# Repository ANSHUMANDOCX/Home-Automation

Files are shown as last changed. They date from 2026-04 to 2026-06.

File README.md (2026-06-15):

# ESP32 Home automation
## Description 
- This is a ESP32 S3 Based Home Automation devices which has 6 Relay switches that can be controlled over the web 
- It also has a BME280 Sensor for monitoring temprature,humidity and pressure in the realtime and can be monitored using a mobile app or a Webpage.
- Also had a FTDI header for easy programming
- Along with web control there is provison to add any physical switches and the case has space to add touch switches too
## Parts Used
- ESP32 S3
- BME280 Sensor
- 6 relays
- Hi-Link 20w 5v AC-DC converter
## Usage 
it is very simple to use just need to plugin the FTDI programmer and Upload the code after adding your SSID nad password so that it will work and on you browser open 192.168.1.100 ive set this as the static IP for accessing the webpage running on the ESP

## PCB Schematic and CAD 




## BUILD 
WhatsApp Image 2026-06-16 at 12 44 00 AM (1)
WhatsApp Image 2026-06-16 at 12 43 59 AM
WhatsApp Image 2026-06-16 at 12 43 42 AM
WhatsApp Image 2026-06-16 at 12 43 41 AM
WhatsApp Image 2026-06-16 at 12 44 00 AM
WhatsApp Image 2026-06-16 at 12 44 00 AM (2)


demo link https://drive.google.com/file/d/14zfI7igBqzAfgmiqQ8RciHNbKA9al0T5/view?usp=sharing

## BOM 
| Name | Purpose | Quantity | Total Cost (USD) | Link | Distributor |
|---|---|---|---|---|---|
| Passive Components | Ressitor and ETC | 1 | 3.00 | | LCSC |
| BWGMRJWX50-10WJ | Antenna Stem | 1 | 0.94 | | LCSC |
| BWIPX1-SMA-1.13L100 | Antenna | 1 | 0.94 | | LCSC |
| MIC5219-3.3YM5-TD | 3.3v Regulator | 1 | 1.23 | https://www.lcsc.com/product-detail/C42422052.html | LCSC |
| SMBJ5.0A | TVS diode | 1 | 0.50 | https://www.lcsc.com/product-detail/C83333.html | LCSC |
| DB128V-5.0-2P-BK-S | Terminal Block 2P | 1 | 0.80 | https://www.lcsc.com/product-detail/C424692.html | LCSC |
| 1N4007 M7 | Diode | 1 | 0.64 | https://www.lcsc.com/product-detail/C20754788.html | LCSC |
| TS665CJ | Switch | 1 | 0.83 | https://www.lcsc.com/product-detail/C393938.html | LCSC |
| DB128V-5.08-3P-GN-S | Terminal Block 3P | 1 | 1.45 | https://www.lcsc.com/product-detail/C2915640.html | LCSC |
| MOV14D471K206RV080 | its a MOV for protection | 1 | 0.52 | https://www.lcsc.com/product-detail/C22390366.html | LCSC |
| ESP32-S3-WROOM-1-N4 | the brains | 1 | 4.64 | https://www.lcsc.com/product-detail/C2913197.html | LCSC |
| BME280 | Sensor | 1 | 7.24 | https://www.lcsc.com/product-detail/C92489.html | LCSC |
| Relay 5v | to switch | 6 | 2.88 | https://www.lcsc.com/product-detail/C35449.html | LCSC |
| PC817C | optocoupler | 1 | 0.55 | https://www.lcsc.com/product-detail/C20612594.html | LCSC |
| HLK-20M05 | onboard 5v | 1 | 4.58 | https://www.lcsc.com/product-detail/C465406.html | LCSC |

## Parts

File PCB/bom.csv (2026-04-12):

Designator | Footprint | Quantity | Value | LCSC Part #
C1 | 0603 | 1 | 1uF
C10 | 0603 | 1 | 10uf
C11 | 0603 | 1 | 100nf
C12, C13, C14, C15, C16, C18, C2, C20, C3, C4, C6, C7, C8, C9 | 0603 | 14 | 0.1uF
C17, C19 | 0603 | 2 | 4.7uf
C5 | 0603 | 1 | 22uF
CN1, CN2, CN3, CN4, CN5, CN6 | CONN-TH_3P-P5.08_DIBO_DB128V-5.08-3P-X | 6 | ~
D1, D2, D3, D4, D5, D6 | D_SMA | 6 | 1N4007
D10, D11, D12, D14, D7, D8, D9 | 0805 | 7 | LED
D13 | 0603 | 1 | LED
D16 | SMB_L4.6-W3.6-LS5.3-RD | 1 | ~
J1 | PinHeader_1x02_P2.54mm_Vertical | 1 | S1
J2, J5, J6 | PinHeader_1x02_P2.54mm_Vertical | 3 | S2
J3 | PinHeader_1x02_P2.54mm_Vertical | 1 | S3
J4 | PinHeader_1x02_P2.54mm_Vertical | 1 | S4
J7 | PinHeader_1x06_P2.54mm_Vertical | 1 | FTDI Pins
J8 | TerminalBlock_CUI_TB007-508-02_1x02_P5.08mm_Horizontal | 1 | AC IN
Q10, Q11, Q6, Q7, Q8, Q9 | SOT-23 | 6 | BC847
Q3, Q4 | SOT-23 | 2 | SS8050
R1, R10, R11, R14, R15, R18, R19, R22, R23, R3, R6, R7 | 0603 | 12 | 220R
R12, R16, R2, R20, R24, R8 | 0603 | 6 | 1K
R13, R17, R21, R4, R5, R9 | 0603 | 6 | DNP
R25, R26, R27, R28, R31, R33, R34, R35, R36, R37, R38 | 0603 | 11 | 10K
R29 | RES-TH_L16.0-W5.2-P7.50-D0.8-S4.20 | 1 | 430pF@1kHz
R30, R32 | 0603 | 2 | 4.7K
RLY1, RLY2, RLY3, RLY4, RLY5, RLY6 | RELAY-TH_SRD-XXVDC-XL-C | 6 | ~
SW1, SW4, SW5, SW6, SW7, SW8 | SW-TH_4P-L6.0-W6.0-P4.50-LS6.5 | 6 | ~
SW2, SW3 | SW_Push_SPST_NO_Alps_SKRK | 2 | SW_Push
U1 | ESP32-S3-WROOM-1 | 1 | ESP32-S3-WROOM-1
U11 | SOT-23-5 | 1 | MIC5219-3.3YM5
U2 | PWRM-TH_HLK-20MXX | 1 | ~
U3, U4, U5, U6, U7, U8 | DIP-4_W7.62mm | 6 | PC817
U9 | Bosch_LGA-8_2.5x2.5mm_P0.65mm_ClockwisePinNumbering | 1 | BME280

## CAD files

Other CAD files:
CAD/Top.f3z

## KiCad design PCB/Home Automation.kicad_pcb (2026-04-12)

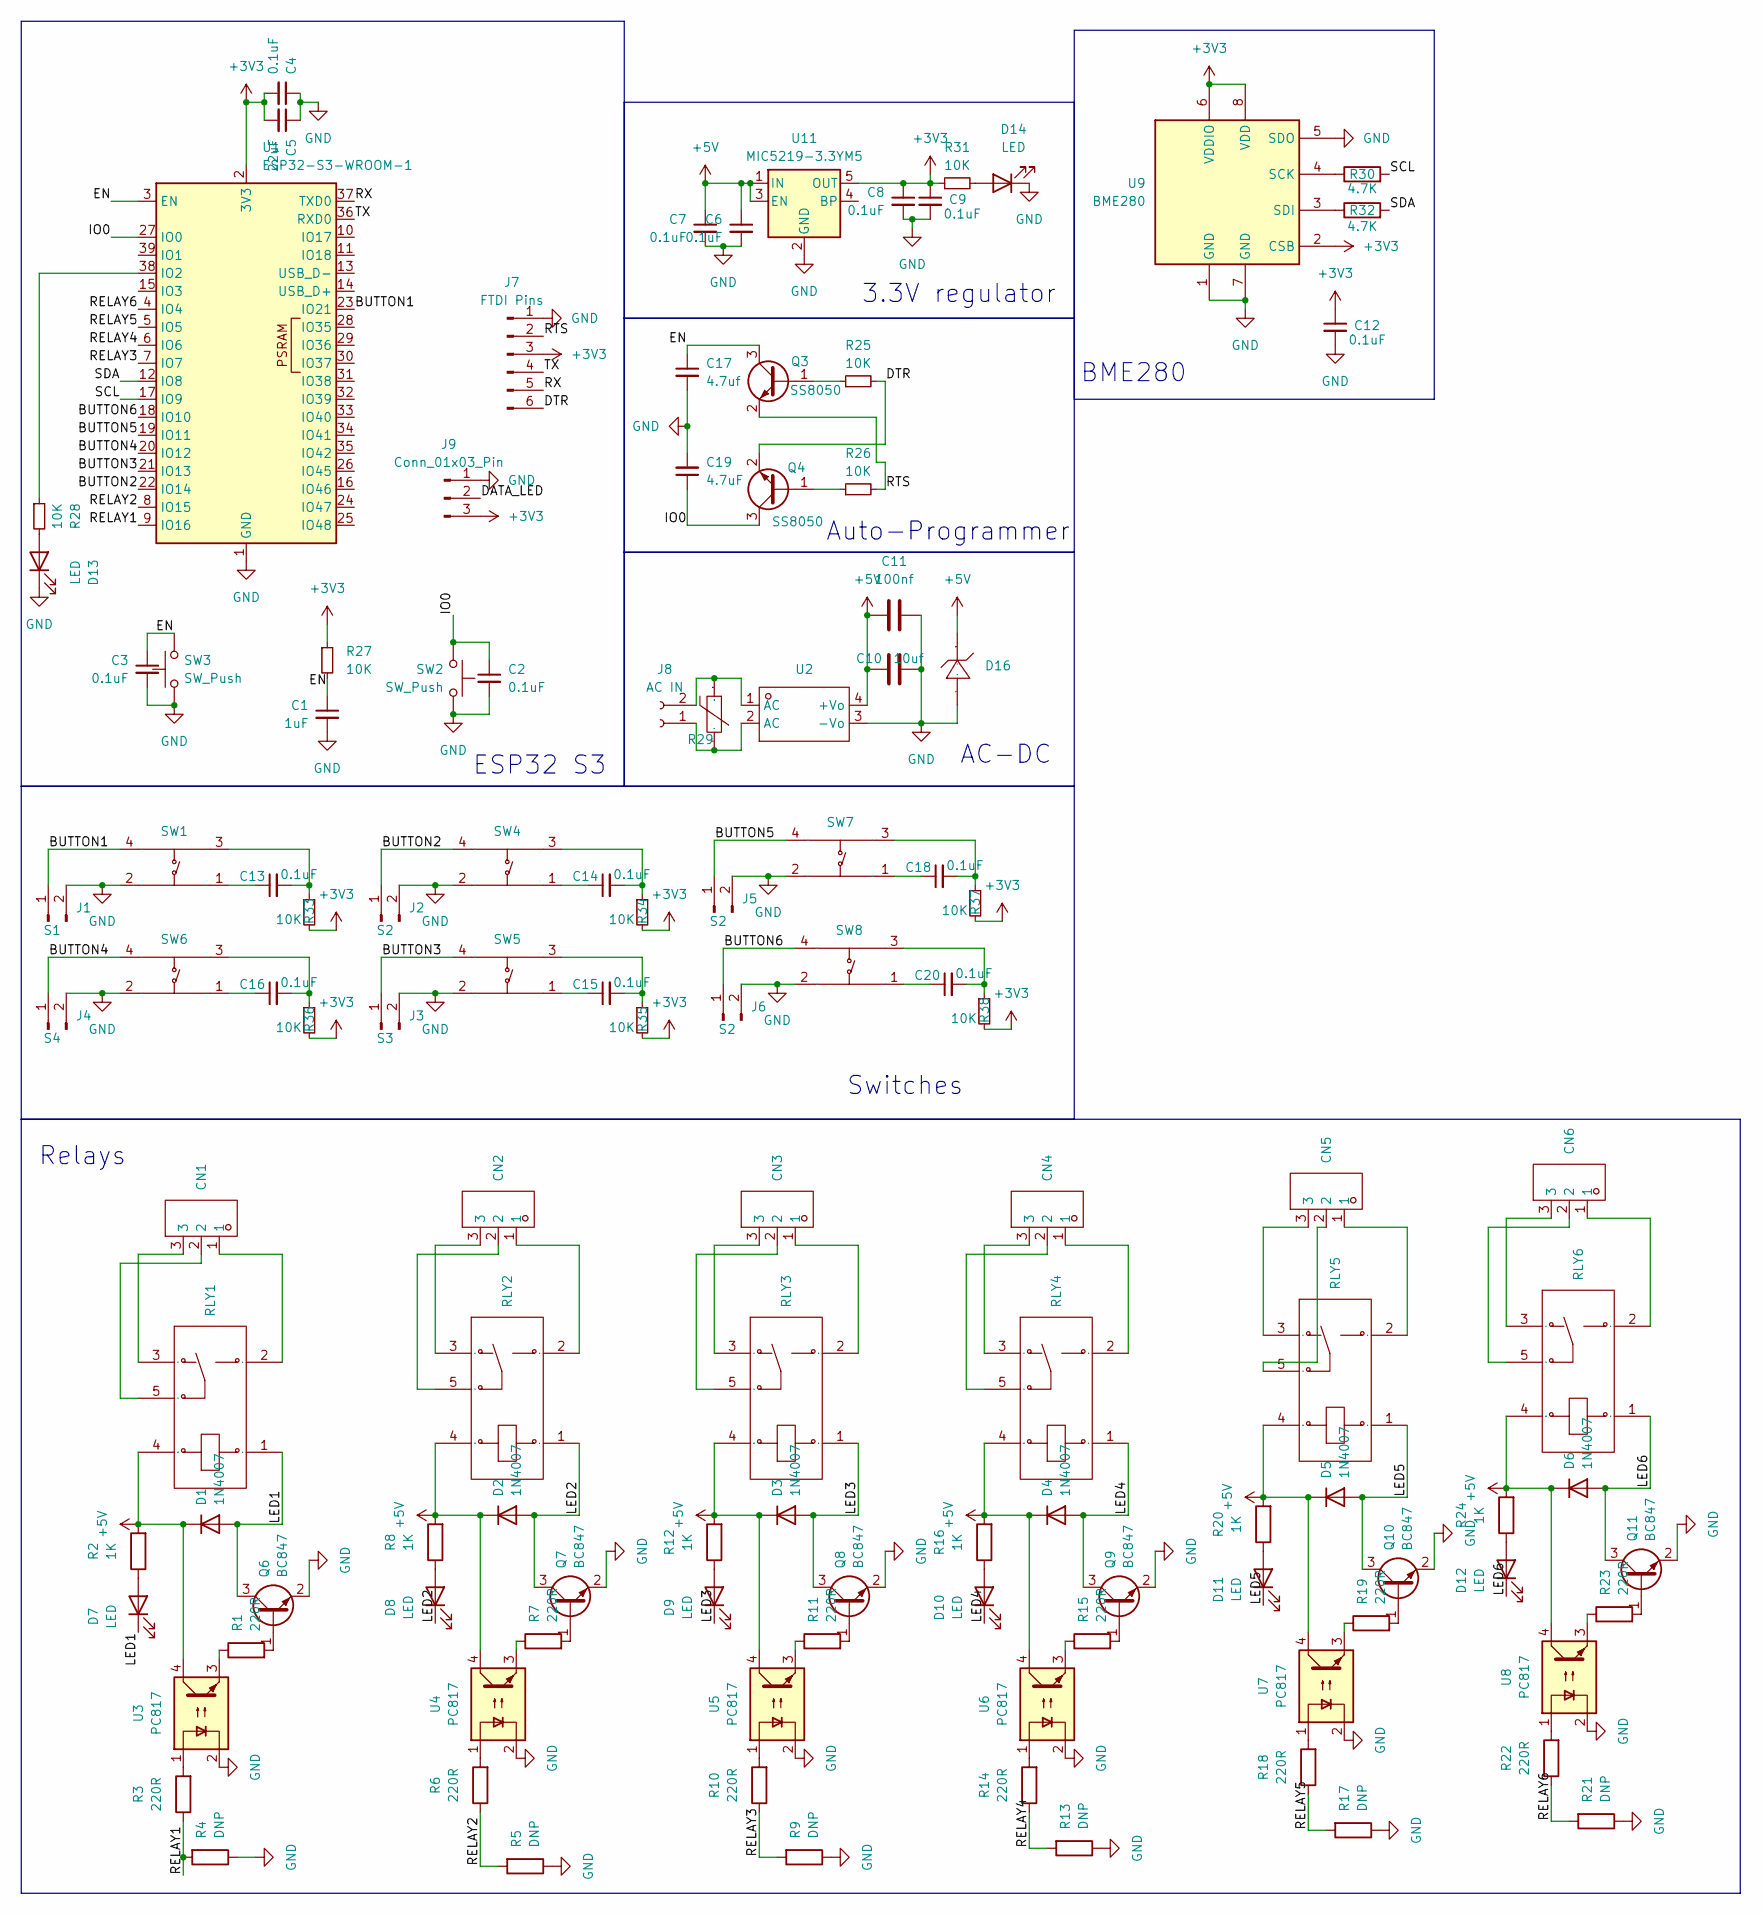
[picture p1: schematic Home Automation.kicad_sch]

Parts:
C1: 1uF; C_0603_1608Metric
C2, C3, C4, C6, C7, C8, C9, C12, C13, C14, C15, C16, C18, C20: 0.1uF; C_0603_1608Metric
C5: 22uF; C_0603_1608Metric
C10: 10uf; C_0603_1608Metric
C11: 100nf; C_0603_1608Metric
C17: 4.7uf; C_0603_1608Metric_Pad1.08x0.95mm_HandSolder
C19: 4.7uF; C_0603_1608Metric_Pad1.08x0.95mm_HandSolder
CN1, CN2, CN3, CN4, CN5, CN6: CONN-TH_3P-P5.08_DIBO_DB128V-5.08-3P-X; Manufacturer Part DB128V-5.08-3P-GN-S; LCSC Part Name 1x3P 5.08mm 直插 排数:1 每排P数:3
D1, D2, D3, D4, D5, D6: 1N4007; D_SMA
D7, D8, D9, D10, D11, D12, D14: LED; LED_0805_2012Metric
D13: LED; LED_0603_1608Metric_Pad1.05x0.95mm_HandSolder
D16: SMB_L4.6-W3.6-LS5.3-RD; Manufacturer Part SMBJ5.0A; LCSC Part Name SMBJ5.0A
J1: S1; PinHeader_1x02_P2.54mm_Vertical
J2, J5, J6: S2; PinHeader_1x02_P2.54mm_Vertical
J3: S3; PinHeader_1x02_P2.54mm_Vertical
J4: S4; PinHeader_1x02_P2.54mm_Vertical
J7: FTDI Pins; PinHeader_1x06_P2.54mm_Vertical
J8: AC IN; TerminalBlock_CUI_TB007-508-02_1x02_P5.08mm_Horizontal
J9: Conn_01x03_Pin; PinHeader_1x03_P2.54mm_Vertical
Q3, Q4: SS8050; SOT-23
Q6, Q7, Q8, Q9, Q10, Q11: BC847; SOT-23
R1, R3, R6, R7, R10, R11, R14, R15, R18, R19, R22, R23: 220R; R_0603_1608Metric
R2, R8, R12, R16, R20, R24: 1K; R_0603_1608Metric
R4, R5, R9, R13, R17, R21: DNP; R_0603_1608Metric
R25, R26: 10K; R_0603_1608Metric_Pad0.98x0.95mm_HandSolder
R27, R28, R31, R33, R34, R35, R36, R37, R38: 10K; R_0603_1608Metric
R29: 430pF@1kHz; RES-TH_L16.0-W5.2-P7.50-D0.8-S4.20; Manufacturer Part MOV14D471K206RV080; LCSC Part Name 14D471K
R30, R32: 4.7K; R_0603_1608Metric
RLY1, RLY2, RLY3, RLY4, RLY5, RLY6: RELAY-TH_SRD-XXVDC-XL-C; Manufacturer Part SRD-05VDC-SL-C; LCSC Part Name 蓝色 单组转换型继电器
SW1, SW4, SW5, SW6, SW7, SW8: SW-TH_4P-L6.0-W6.0-P4.50-LS6.5; Manufacturer Part TS665CJ; LCSC Part Name 6*6*5mm 直插 轻触开关
SW2, SW3: SW_Push; SW_Push_SPST_NO_Alps_SKRK
U1: ESP32-S3-WROOM-1
U2: PWRM-TH_HLK-20MXX; Manufacturer Part HLK-20M05; LCSC Part Name 20W超紧凑型电源模块系列
U3, U4, U5, U6, U7, U8: PC817; DIP-4_W7.62mm
U9: BME280; Bosch_LGA-8_2.5x2.5mm_P0.65mm_ClockwisePinNumbering
U11: MIC5219-3.3YM5; SOT-23-5

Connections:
+3V3: C4.2, C5.2, C8.1, C9.1, C12.1, J7.3, J9.3, R27.1, R31.1, R33.2, R34.2, R35.2, R36.2, R37.2, R38.2, U1.2 (3V3), U9.2 (CSB), U9.6 (VDDIO), U9.8 (VDD), U11.5 (OUT)
+5V: C6.1, C7.1, C10.1, C11.1, D1.1 (K), D2.1 (K), D3.1 (K), D4.1 (K), D5.1 (K), D6.1 (K), D16.1 (C), R2.2, R8.2, R12.2, R16.2, R20.2, R24.2, RLY1.4, RLY2.4, RLY3.4, RLY4.4, RLY5.4, RLY6.4, U2.4 (+Vo), U3.4, U4.4, U5.4, U6.4, U7.4, U8.4, U11.1 (IN), U11.3 (EN)
/BUTTON1: J1.1, SW1.4 (D), U1.23 (IO21)
/BUTTON2: J2.1, SW4.4 (D), U1.22 (IO14)
/BUTTON3: J3.1, SW5.4 (D), U1.21 (IO13)
/BUTTON4: J4.1, SW6.4 (D), U1.20 (IO12)
/BUTTON5: J5.1, SW7.4 (D), U1.19 (IO11)
/BUTTON6: J6.1, SW8.4 (D), U1.18 (IO10)
/DTR: J7.6, Q4.2 (E), R25.2
/EN: C1.1, C3.1, C17.1, Q3.3 (C), R27.2, SW3.2, U1.3 (EN)
/IO0: C2.1, C19.1, Q4.3 (C), SW2.2, U1.27 (IO0)
/LED1: D1.2 (A), D7.1 (K), Q6.3 (C), RLY1.1
/LED2: D2.2 (A), D8.1 (K), Q7.3 (C), RLY2.1
/LED3: D3.2 (A), D9.1 (K), Q8.3 (C), RLY3.1
/LED4: D4.2 (A), D10.1 (K), Q9.3 (C), RLY4.1
/LED5: D5.2 (A), D11.1 (K), Q10.3 (C), RLY5.1
/LED6: D6.2 (A), D12.1 (K), Q11.3 (C), RLY6.1
/RELAY1: R3.1, R4.2, U1.9 (IO16)
/RELAY2: R5.2, R6.1, U1.8 (IO15)
/RELAY3: R9.2, R10.1, U1.7 (IO7)
/RELAY4: R13.2, R14.1, U1.6 (IO6)
/RELAY5: R17.2, R18.1, U1.5 (IO5)
/RELAY6: R21.2, R22.1, U1.4 (IO4)
/RTS: J7.2, Q3.2 (E), R26.2
/RX: J7.5, U1.37 (TXD0)
/SCL: R30.2, U1.17 (IO9)
/SDA: R32.2, U1.12 (IO8)
/TX: J7.4, U1.36 (RXD0)
GND: C1.2, C2.2, C3.2, C4.1, C5.1, C6.2, C7.2, C8.2, C9.2, C10.2, C11.2, C12.2, C17.2, C19.2, D13.1 (K), D14.1 (K), D16.2 (A), J1.2, J2.2, J3.2, J4.2, J5.2, J6.2, J7.1, J9.1, Q6.2 (E), Q7.2 (E), Q8.2 (E), Q9.2 (E), Q10.2 (E), Q11.2 (E), R4.1, R5.1, R9.1, R13.1, R17.1, R21.1, SW1.2 (B), SW2.1, SW3.1, SW4.2 (B), SW5.2 (B), SW6.2 (B), SW7.2 (B), SW8.2 (B), U1.1 (GND), U1.40 (GND), U1.41 (GND), U2.3 (-Vo), U3.2, U4.2, U5.2, U6.2, U7.2, U8.2, U9.1 (GND), U9.5 (SDO), U9.7 (GND), U11.2 (GND)
unnamed: CN1.1, RLY1.2
unnamed: CN1.2, RLY1.5
unnamed: CN1.3, RLY1.3
unnamed: CN2.1, RLY2.2
unnamed: CN2.2, RLY2.5
unnamed: CN2.3, RLY2.3
unnamed: CN3.1, RLY3.2
unnamed: CN3.2, RLY3.5
unnamed: CN3.3, RLY3.3
unnamed: CN4.1, RLY4.2
unnamed: CN4.2, RLY4.5
unnamed: CN4.3, RLY4.3
unnamed: CN5.1, RLY5.2
unnamed: CN5.2, RLY5.5
unnamed: CN5.3, RLY5.3
unnamed: CN6.1, RLY6.2
unnamed: CN6.2, RLY6.5
unnamed: CN6.3, RLY6.3
unnamed: D7.2 (A), R2.1
unnamed: D8.2 (A), R8.1
unnamed: D9.2 (A), R12.1
unnamed: D10.2 (A), R16.1
unnamed: D11.2 (A), R20.1
unnamed: D12.2 (A), R24.1
unnamed: D13.2 (A), R28.2
unnamed: D14.2 (A), R31.2
unnamed: Q3.1 (B), R25.1
unnamed: Q4.1 (B), R26.1
unnamed: Q6.1 (B), R1.2
unnamed: Q7.1 (B), R7.2
unnamed: Q8.1 (B), R11.2
unnamed: Q9.1 (B), R15.2
unnamed: Q10.1 (B), R19.2
unnamed: Q11.1 (B), R23.2
unnamed: R1.1, U3.3
unnamed: R3.2, U3.1
unnamed: R6.2, U4.1
unnamed: R7.1, U4.3
unnamed: R10.2, U5.1
unnamed: R11.1, U5.3
unnamed: R14.2, U6.1
unnamed: R15.1, U6.3
unnamed: R18.2, U7.1
unnamed: R19.1, U7.3
unnamed: R22.2, U8.1
unnamed: R23.1, U8.3
unnamed: C13.1, SW1.1 (A)
unnamed: C13.2, R33.1, SW1.3 (C)
unnamed: C14.1, SW4.1 (A)
unnamed: C14.2, R34.1, SW4.3 (C)
unnamed: C15.1, SW5.1 (A)
unnamed: C15.2, R35.1, SW5.3 (C)
unnamed: C16.1, SW6.1 (A)
unnamed: C16.2, R36.1, SW6.3 (C)
unnamed: C18.1, SW7.1 (A)
unnamed: C18.2, R37.1, SW7.3 (C)
unnamed: C20.1, SW8.1 (A)
unnamed: C20.2, R38.1, SW8.3 (C)
unnamed: R28.1, U1.38 (IO2)
unnamed: R30.1, U9.4 (SCK)
unnamed: R32.1, U9.3 (SDI)

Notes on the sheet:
AC-DC
Relays
BME280
Switches
ESP32 S3
Auto-Programmer
3.3V regulator

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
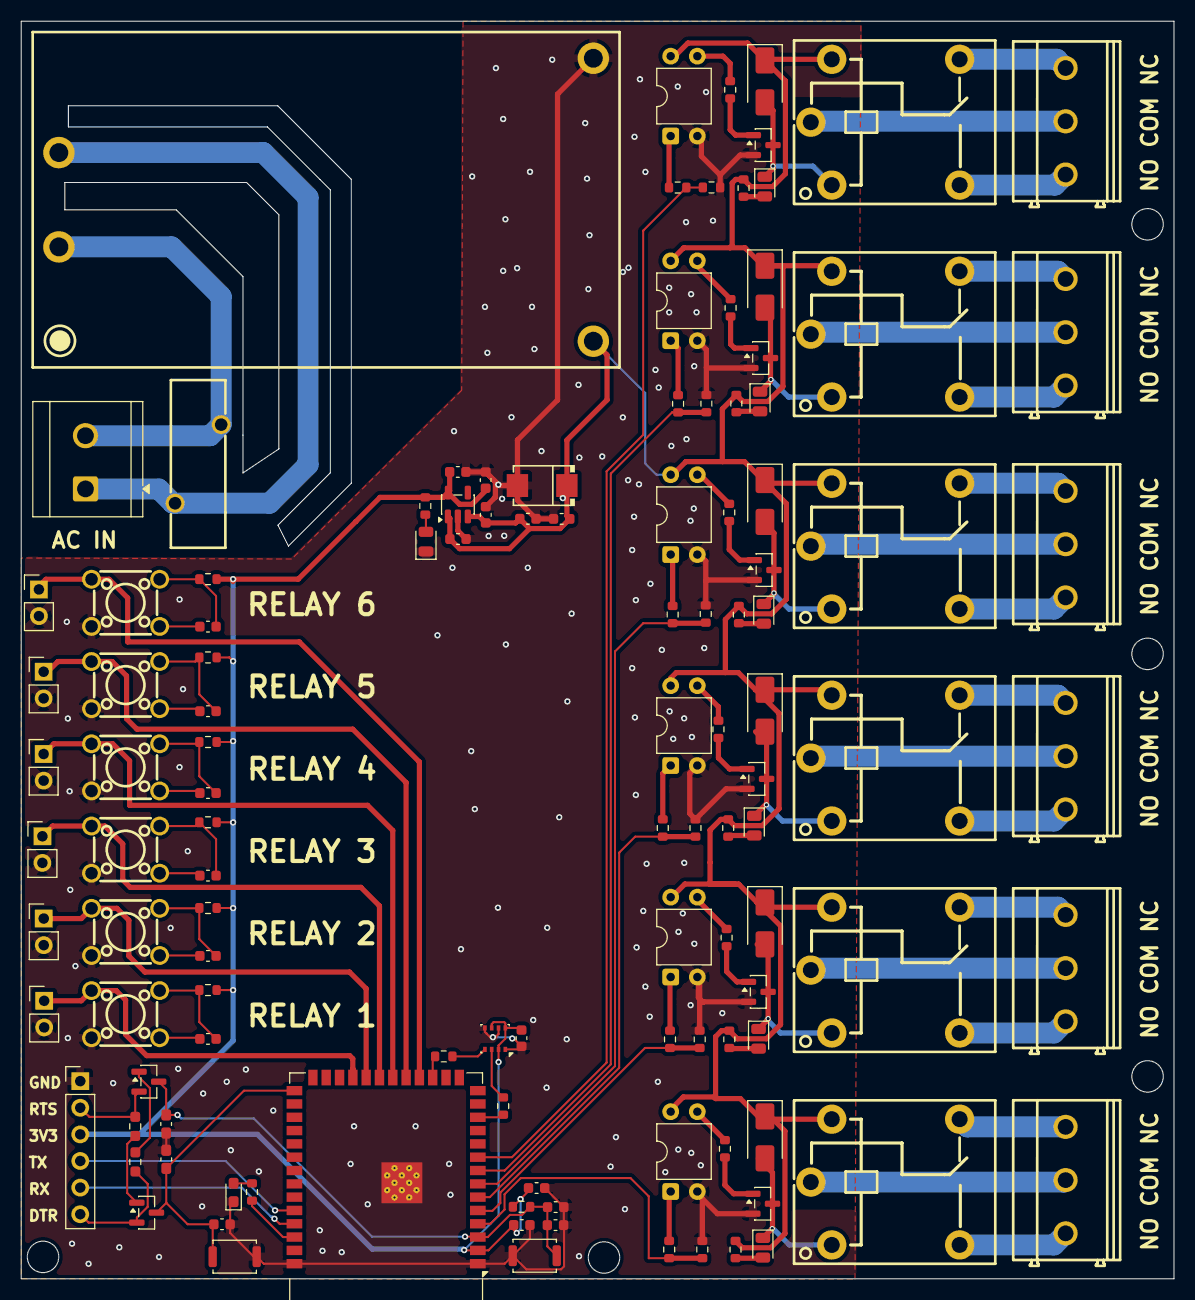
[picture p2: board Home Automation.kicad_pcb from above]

Board: 2 copper layers, 110.0 x 120.0 mm, 119 parts (0 on the bottom side), 92 nets.

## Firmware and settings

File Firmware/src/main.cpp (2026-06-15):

/*
  Relay Controller — ESP32-S3-WROOM-1
  ─────────────────────────────────────
  • 6 relays controlled via web UI + onboard buttons
  • Buttons are active-LOW (10K pull-up to 3V3, 0.1uF debounce cap)
  • Relay outputs are active-HIGH (BC847 NPN driver)
  • Web server on port 80, served from PROGMEM
  • WebSocket for real-time state sync between page and board

  Pin mapping (from schematic):
    RELAY1 → IO15    BUTTON1 → IO38
    RELAY2 → IO8     BUTTON2 → IO33
    RELAY3 → IO7     BUTTON3 → IO21
    RELAY4 → IO6     BUTTON4 → IO20
    RELAY5 → IO5     BUTTON5 → IO19
    RELAY6 → IO4     BUTTON6 → IO18
*/

#include <WiFi.h>
#include <AsyncTCP.h>
#include <ESPAsyncWebServer.h>
#include <ArduinoJson.h>

// ── Credentials ────────────────────────────────────────────────
const char* WIFI_SSID = "SSID";
const char* WIFI_PASS = "PASSWORD";

// ── Pin definitions ─────────────────────────────────────────────
const uint8_t RELAY_PINS[6] = {16, 15,7, 6, 5, 4};
const uint8_t BTN_PINS[6]   = {21, 14, 13, 12, 11, 10};

// ── State ───────────────────────────────────────────────────────
bool relayState[6] = {false};

// Debounce
uint32_t lastDebounce[6]  = {0};
bool     lastBtnRaw[6]    = {true};   // HIGH = unpressed (pull-up)
bool     btnState[6]      = {true};
const uint32_t DEBOUNCE_MS = 50;

AsyncWebServer server(80);
AsyncWebSocket ws("/ws");

// ── HTML (stored in flash) ──────────────────────────────────────
const char INDEX_HTML[] PROGMEM = R"rawliteral(
<!DOCTYPE html>
<html lang="en">
<head>
<meta charset="UTF-8">
<meta name="viewport" content="width=device-width, initial-scale=1">
<title>Relay Controller</title>
<style>
  @import url('https://fonts.googleapis.com/css2?family=JetBrains+Mono:wght@400;700&family=Inter:wght@400;500;600&display=swap');

  *, *::before, *::after { box-sizing: border-box; margin: 0; padding: 0; }

  :root {
    --bg:       #0d0f14;
    --surface:  #161a22;
    --border:   #252a35;
    --text:     #c8cdd8;
    --dim:      #5a6070;
    --on:       #00e5a0;
    --on-glow:  rgba(0,229,160,0.18);
    --off:      #2a2f3a;
    --accent:   #4f8eff;
    --mono:     'JetBrains Mono', monospace;
    --sans:     'Inter', sans-serif;
  }

  body {
    background: var(--bg);
    color: var(--text);
    font-family: var(--sans);
    min-height: 100vh;
    display: flex;
    flex-direction: column;
    align-items: center;
    padding: 2rem 1rem 3rem;
  }

  header {
    width: 100%;
    max-width: 640px;
    display: flex;
    justify-content: space-between;
    align-items: center;
    margin-bottom: 2.5rem;
  }

  .logo {
    font-family: var(--mono);
    font-size: 0.75rem;
    letter-spacing: 0.15em;
    color: var(--dim);
    text-transform: uppercase;
  }

  .logo span { color: var(--on); }

  #status-dot {
    width: 8px; height: 8px;
    border-radius: 50%;
    background: var(--dim);
    display: inline-block;
    margin-right: 6px;
    transition: background 0.3s;
  }
  #status-dot.connected { background: var(--on); box-shadow: 0 0 6px var(--on); }

  #status-label {
    font-family: var(--mono);
    font-size: 0.7rem;
    color: var(--dim);
    letter-spacing: 0.1em;
  }

  .grid {
    display: grid;
    grid-template-columns: repeat(2, 1fr);
    gap: 1rem;
    width: 100%;
    max-width: 640px;
  }

  @media (min-width: 500px) {
    .grid { grid-template-columns: repeat(3, 1fr); }
  }

  .relay-card {
    background: var(--surface);
    border: 1px solid var(--border);
    border-radius: 12px;
    padding: 1.25rem 1rem 1rem;
    display: flex;
    flex-direction: column;
    align-items: center;
    gap: 0.85rem;
    cursor: pointer;
    transition: border-color 0.2s, box-shadow 0.2s, transform 0.1s;
    user-select: none;
    -webkit-tap-highlight-color: transparent;
  }

  .relay-card:active { transform: scale(0.97); }

  .relay-card.on {
    border-color: var(--on);
    box-shadow: 0 0 0 1px var(--on), inset 0 0 32px var(--on-glow);
  }

  .relay-num {
    font-family: var(--mono);
    font-size: 0.65rem;
    letter-spacing: 0.15em;
    color: var(--dim);
    text-transform: uppercase;
  }

  .relay-icon {
    width: 48px; height: 48px;
    position: relative;
  }

  /* SVG coil relay icon — drawn inline per card via JS */
  .relay-icon svg { width: 100%; height: 100%; }

  .relay-label {
    font-size: 0.8rem;
    font-weight: 600;
    letter-spacing: 0.05em;
  }

  .relay-badge {
    font-family: var(--mono);
    font-size: 0.65rem;
    letter-spacing: 0.12em;
    padding: 2px 8px;
    border-radius: 4px;
    background: var(--off);
    color: var(--dim);
    transition: background 0.2s, color 0.2s;
  }

  .relay-card.on .relay-badge {
    background: var(--on);
    color: #000;
  }

  .controls {
    margin-top: 1.75rem;
    display: flex;
    gap: 0.75rem;
    width: 100%;
    max-width: 640px;
  }

  .btn {
    flex: 1;
    padding: 0.65rem;
    border-radius: 8px;
    border: 1px solid var(--border);
    background: var(--surface);
    color: var(--text);
    font-family: var(--mono);
    font-size: 0.72rem;
    letter-spacing: 0.1em;
    cursor: pointer;
    transition: border-color 0.2s, color 0.2s;
  }

  .btn:hover { border-color: var(--accent); color: var(--accent); }

  .io-row {
    margin-top: 1rem;
    width: 100%;
    max-width: 640px;
    background: var(--surface);
    border: 1px solid var(--border);
    border-radius: 8px;
    padding: 0.75rem 1rem;
    font-family: var(--mono);
    font-size: 0.68rem;
    color: var(--dim);
    letter-spacing: 0.05em;
    display: flex;
    justify-content: space-between;
    flex-wrap: wrap;
    gap: 0.4rem;
  }

  .io-row span { color: var(--text); }
</style>
</head>
<body>

<header>
  <div class="logo">ESP32-S3 &nbsp;/&nbsp; <span>Relays</span></div>
  <div>
    <span id="status-dot"></span>
    <span id="status-label">CONNECTING</span>
  </div>
</header>

<div class="grid" id="grid"></div>

<div class="controls">
  <button class="btn" onclick="allOn()">ALL ON</button>
  <button class="btn" onclick="allOff()">ALL OFF</button>
</div>

<div class="io-row" id="io-row">
  Loading pin map…
</div>

<script>
const RELAY_PINS = [15, 8, 7, 6, 5, 4];
const BTN_PINS   = [38, 33, 21, 20, 19, 18];
const N = 6;
let states = Array(N).fill(false);
let ws;

// ── Build cards ──────────────────────────────────────────────
const grid = document.getElementById('grid');
for (let i = 0; i < N; i++) {
  const card = document.createElement('div');
  card.className = 'relay-card';
  card.id = `r${i}`;
  card.innerHTML = `
    <div class="relay-num">RLY ${i+1}</div>
    <div class="relay-icon">
      <svg viewBox="0 0 48 48" fill="none" xmlns="http://www.w3.org/2000/svg">
        <!-- coil -->
        <rect x="8" y="20" width="32" height="8" rx="2"
              fill="none" stroke="currentColor" stroke-width="1.5"/>
        <line x1="16" y1="20" x2="16" y2="28" stroke="currentColor" stroke-width="1.2"/>
        <line x1="22" y1="20" x2="22" y2="28" stroke="currentColor" stroke-width="1.2"/>
        <line x1="28" y1="20" x2="28" y2="28" stroke="currentColor" stroke-width="1.2"/>
        <!-- armature -->
        <line id="arm${i}" x1="4" y1="15" x2="24" y2="15"
              stroke="currentColor" stroke-width="2" stroke-linecap="round"/>
        <!-- contact -->
        <circle cx="36" cy="11" r="2.5" fill="none"
                stroke="currentColor" stroke-width="1.5"/>
        <circle cx="36" cy="18" r="2.5" fill="none"
                stroke="currentColor" stroke-width="1.5"/>
        <!-- leads -->
        <line x1="4" y1="24" x2="4" y2="15" stroke="currentColor" stroke-width="1.5"/>
        <line x1="36" y1="8" x2="36" y2="8.5" stroke="currentColor" stroke-width="1.5"/>
        <line x1="36" y1="20.5" x2="36" y2="40" stroke="currentColor" stroke-width="1.5"/>
      </svg>
    </div>
    <div class="relay-label">Relay ${i+1}</div>
    <div class="relay-badge" id="b${i}">OFF</div>`;
  card.addEventListener('click', () => toggle(i));
  grid.appendChild(card);
}

// IO pin map row
document.getElementById('io-row').innerHTML =
  RELAY_PINS.map((p,i)=>`RLY${i+1}:<span>IO${p}</span>`).join(' &nbsp; ') +
  '&nbsp;&nbsp;|&nbsp;&nbsp;' +
  BTN_PINS.map((p,i)=>`BTN${i+1}:<span>IO${p}</span>`).join(' &nbsp; ');

// ── WebSocket ────────────────────────────────────────────────
function connect() {
  ws = new WebSocket(`ws://${location.hostname}/ws`);

  ws.onopen = () => {
    document.getElementById('status-dot').className = 'connected';
    document.getElementById('status-label').textContent = 'LIVE';
  };

  ws.onclose = () => {
    document.getElementById('status-dot').className = '';
    document.getElementById('status-label').textContent = 'RECONNECTING…';
    setTimeout(connect, 2000);
  };

  ws.onmessage = e => {
    const msg = JSON.parse(e.data);
    if (msg.type === 'state') {
      msg.relays.forEach((v, i) => setUI(i, v));
    }
  };
}

function send(obj) {
  if (ws && ws.readyState === WebSocket.OPEN)
    ws.send(JSON.stringify(obj));
}

// ── UI helpers ───────────────────────────────────────────────
function setUI(i, on) {
  states[i] = on;
  const card = document.getElementById(`r${i}`);
  const badge = document.getElementById(`b${i}`);
  card.classList.toggle('on', on);
  badge.textContent = on ? 'ON' : 'OFF';
}

function toggle(i) {
  send({ type: 'toggle', relay: i });
}

function allOn()  { send({ type: 'all', value: true  }); }
function allOff() { send({ type: 'all', value: false }); }

connect();
</script>
</body>
</html>
)rawliteral";


// ── WebSocket broadcast ─────────────────────────────────────────
void broadcastState() {
  StaticJsonDocument<128> doc;
  doc["type"] = "state";
  JsonArray arr = doc.createNestedArray("relays");
  for (int i = 0; i < 6; i++) arr.add(relayState[i]);
  String out;
  serializeJson(doc, out);
  ws.textAll(out);
}

void setRelay(int i, bool on) {
  relayState[i] = on;
  digitalWrite(RELAY_PINS[i], on ? HIGH : LOW);
}

// ── WebSocket event handler ─────────────────────────────────────
void onWsEvent(AsyncWebSocket* s, AsyncWebSocketClient* client,
               AwsEventType type, void* arg, uint8_t* data, size_t len) {
  if (type == WS_EVT_CONNECT) {
    broadcastState();  // send current state to new client
  } else if (type == WS_EVT_DATA) {
    AwsFrameInfo* info = (AwsFrameInfo*)arg;
    if (info->final && info->opcode == WS_TEXT) {
      data[len] = '\0';
      StaticJsonDocument<128> doc;
      if (deserializeJson(doc, (char*)data)) return;

      const char* msgType = doc["type"];
      if (strcmp(msgType, "toggle") == 0) {
        int idx = doc["relay"];
        if (idx >= 0 && idx < 6) setRelay(idx, !relayState[idx]);
      } else if (strcmp(msgType, "all") == 0) {
        bool v = doc["value"];
        for (int i = 0; i < 6; i++) setRelay(i, v);
      }
      broadcastState();
    }
  }
}

// ── Setup ───────────────────────────────────────────────────────
void setup() {
  Serial.begin(115200);

  // Relay outputs
  for (int i = 0; i < 6; i++) {
    pinMode(RELAY_PINS[i], OUTPUT);
    digitalWrite(RELAY_PINS[i], LOW);
  }

  // Button inputs (external pull-up on board, no internal needed)
  for (int i = 0; i < 6; i++) {
    pinMode(BTN_PINS[i], INPUT);
    lastBtnRaw[i] = digitalRead(BTN_PINS[i]);
    btnState[i]   = lastBtnRaw[i];
  }
// Static IP config — change to match your network
IPAddress local_IP(192, 168, 1, 100);
IPAddress gateway(192, 168, 1, 1);
IPAddress subnet(255, 255, 255, 0);
IPAddress dns(8, 8, 8, 8);  // optional

WiFi.config(local_IP, gateway, subnet, dns);
WiFi.begin(WIFI_SSID, WIFI_PASS);
  // WiFi
  WiFi.begin(WIFI_SSID, WIFI_PASS);
  Serial.print("Connecting to WiFi");
  while (WiFi.status() != WL_CONNECTED) {
    delay(500); Serial.print(".");
  }
  Serial.printf("\nIP: %s\n", WiFi.localIP().toString().c_str());

  // WebSocket
  ws.onEvent(onWsEvent);
  server.addHandler(&ws);

  // HTTP
  server.on("/", HTTP_GET, [](AsyncWebServerRequest* req) {
    req->send_P(200, "text/html", INDEX_HTML);
  });

  server.begin();
  Serial.println("Server started");
}

// ── Loop ────────────────────────────────────────────────────────
void loop() {
  uint32_t now = millis();

  for (int i = 0; i < 6; i++) {
    bool raw = digitalRead(BTN_PINS[i]);

    if (raw != lastBtnRaw[i]) {
      lastDebounce[i] = now;
      lastBtnRaw[i] = raw;
    }

    if ((now - lastDebounce[i]) > DEBOUNCE_MS) {
      if (raw != btnState[i]) {
        btnState[i] = raw;
        // Falling edge = button pressed (active LOW)
        if (btnState[i] == LOW) {
          setRelay(i, !relayState[i]);
          broadcastState();
        }
      }
    }
  }

  ws.cleanupClients();
}
